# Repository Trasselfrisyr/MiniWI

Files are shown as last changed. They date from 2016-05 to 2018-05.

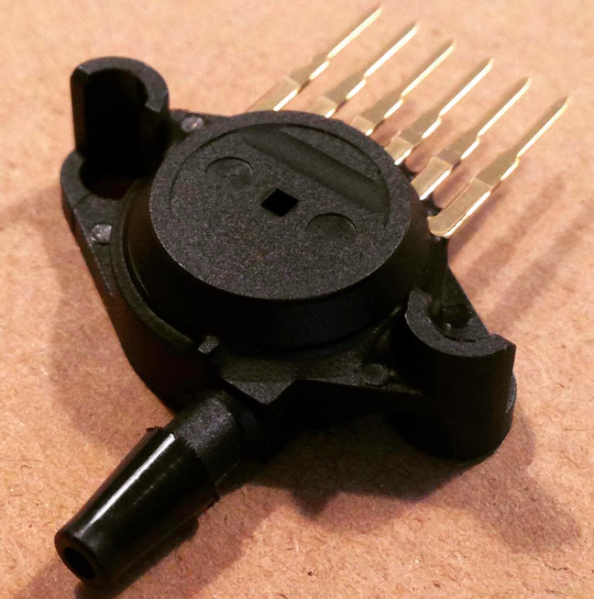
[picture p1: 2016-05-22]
Docs and references/mpx5010gp.png

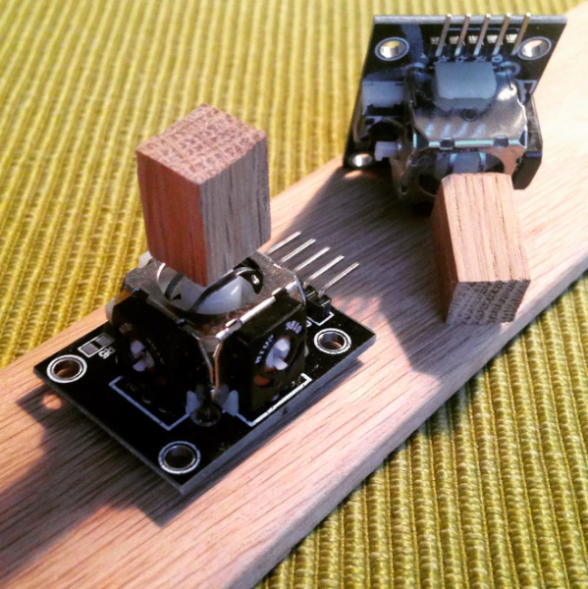
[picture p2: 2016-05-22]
Docs and references/joysticks.png

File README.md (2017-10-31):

# MiniWI
MIDI woodwind controller

2016-04-17

This MIDI controller is running on an Arduino Pro Mini with Atmega328 16MHz/5V. It makes use of breakouts for analog pins A6 and A7, so it needs a Pro Mini version with these breakouts. The pressure sensor used for the project is the Freescale MPX5010GP. Fingering is reverse engineered from Akai EWI and note values are calculated from pressed keys. For details on this, read my guest post on the Gordophone blog. 

http://gordophone.blogspot.se/2016/04/guest-post-alternative-way-of-note.html

Details on the state machine approach for handling the events is also available on Gordon's blog where I borrowed it from. He's got a step-by-step how-to on DIY wind controllers that I highly recommend.

http://gordophone.blogspot.se/2013/01/a-series-basics-of-diy-wind-controllers.html

Hardware notes for connection of MIDI, pressure sensor, keys and joysticks are available in the MiniWI.ino file.

The MIDI routines and the MIDI connections are pretty standard, but I first found them on the midikits.net website, so I'll give Tom Scarff a mention here. Kept his nice MIDI pinout ASCII sketch thing and some comment style too. 

The controller is made to work well with synthesizers using wind controller patches from Patchman Music, with the breath data sent by CC #2 (Breath). For testing I’ve been using their wind controller soundbank for Roland JV-1010.

http://www.patchmanmusic.com

Or you can make your own patches optimized for breath control. Pointers for doing that can also be found on the Patchman website.

Questions and suggestions are welcome. Just send them to johan@helgo.net.

-Johan Berglund

2016-05-17

Variations:

MiniWI.ino is the original proof of concept breadboard version with regular switches.

MiniWI-lite.ino is a simplified version (no joysticks) for my guest post on the Gordophone blog.

MiniWI-cap.ino is the capacitive touch version implemented in my first playable prototype.

MiniWI-cap-pmt.ino is a modification of the touch version to feature portamento (glide) control and a separate potentiometer for setting base octave instead of using sideways motion of joystick to increase range. This reduces instantly playable range but increases the total range of the controller.

MiniVI-cap.ino is a not yet realized EVI version (Electronic Valve Instrument) based on the Akai EVI1000 and the Steiner MIDI EVI.

2016-05-22

I’ve added some pictures from my Instagram account. Check it out for more pictures from this and my other projects.

https://www.instagram.com/trasselfrisyr/

2016-05-30

Project profile for the MiniWI added on Hackaday.io

https://hackaday.io/project/11843-miniwi-woodwind-midi-controller

2016-06-03

Added optional Casio DH 2nd octave fingerings. Default disabled. Set #define casioMod 1 to set default enabled. Hold octave stick up at power on for manual selection of the setting that is not default.

2016-06-12

Added tested and working version of the new TeensieWI, a simplified version for USB MIDI using the built in capacitive touch sensing in the Teensy LC and breath sensing from the MPX5010GP. Small warning here: the breath sensor output is not limited and could reach values near 5V, while the analog input on the Teensy LC is 3.3V and not rated 5V safe. To reach these levels you’d have to blow really, really hard. If you need to feel safe, go with a Teensy 3.1 or 3.2 as they have 5V tolerant inputs. Only minor alterations needed in the code for use with Teensy 3.x (touch sensing on other pins, some as pads on the back).

2017-10-31

Improved the joystick version of the TeensieWI, now called T.WI, with breath response curves and some other stuff that can be configured at plug-in. Started making these for sale on Tindie. https://www.tindie.com/products/yoe/twi-a-teensy-based-usb-midi-woodwind-controller/

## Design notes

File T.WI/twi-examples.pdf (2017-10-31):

# T.WI

examples

GarageBand (Mac)

GarageBand is pretty limited in how much can be configured, but many of its synth patches respond to aftertouch (channel pressure), so setting up the T.WI to send aftertouch makes it useful here. You can even keep the standard CC#2 active when activating aftertouch by holding the second RH key in combination with the pinkie key held for aftertouch.

Examples of useful synth sounds in GarageBand 10 are Saturn Lead and Soft Saw Lead.

Thor (iPad)

Now, Thor is a synth I can highly recommend. It is very flexible in its controller configuration, great sounding and not too pricey. Also there are lots of readymade patches for it intended for use with wind controllers. Patchman Music has pro grade patches (http://www.patchmanmusic.com/PropellerheadThor.html) for it with a bit higher price, but there are other options, like the set by Bernie Kenerson (http://www.berniekenerson.com/sound_design/) or even free patches for download. (http://wx5.blog2.fc2.com/blog-entry-448.html) The free patches are actually really good, but they lack mod wheel response. The Akai EWI is using MIDI pitch bend to create vibrato, so some patches made for EWI just has no mod wheel action programmed. This can be helped with some alterations to the patches of your own, or by setting the T.WI to send pitch bend vibrato by toggling the MOD setting.

To use the T.WI with these Thor patches, have it set up in its default mode, using CC#2 for the breath data.

Seaboard 5D (iPad and iPhone)

This is a free app from Roli, the makers of the expressive Seaboard controller. The Seaboard 5D app responds very well to aftertouch data, as this represents the ”press” dimension of the 5D concept.

To use it with the T.WI, we need to set up both the app and the T.WI for it. In the app, use the top right menu circle, select MIDI setup and choose Teensy MIDI as MIDI input. Select Single channel and Bend Range 12. (See their support page for more info.) (https://support.roli.com/article/all-you-need-to-know-about-seaboard-5d/) Set the T.WI to send breath data as aftertouch (AT), pitch bend (PB) to 1/12 and modulation (MOD) to send vibrato as pitch bend.

Arturia Minibrute (via USB host adapter)

The Minibrute has a connection in history with the T.WI, as the filter in the Minibrute is designed by Nyle Steiner, the same genius that invented the original EVI and EWI. For that reason, I reckon the Minibrute should be included here. Another reason for it is that the T.WI needs to be set up in a rather special way for this combination to work. First of all, the MB is a bit limited in receiving midi control data. It does receive aftertouch that can be routed to control the filter cutoff, but with no smoothing function in the digital to analog conversion for it, there is quite a bit of audible stepping in the sound as a result. The solution is to use the mod wheel control instead, as it is capable of receiving high resolution MIDI CC. That means that in addition to the seven bits of data sent on CC#1, another group of seven bits are sent on CC#33. That’s 14 bits of resolution. In reality, the resolution we get from the Teensy ADC when reading the breath sensor is 12 bits, and 12 bits is what the MB modulation wheel is sending/receiving, but that it still a whole lot more than the standard 7 bits of midi. We get 4096 steps instead of just 128.

The breath setting to use on the T.WI is CC1+33, keys LH1 and LH3 held with PB UP at USB plug-in.

Another limitation in the MB is that pitch bend range when received on MIDI is always 12 semitones up or down. That’s way too much for practical use with an EWI, so we need to compensate for that. The T.WI has two modes for pitch bend. The default one sets pitch bend to half range. Sounds great with synths set to two semitones PB range. The other one is 1/12 of the total range. This is what we will use with the MB.

Hold joystick right and RH2 key at USB plug-in to toggle this setting.

To get the breath response you want when controlling the MB, you can also try different curves for it. I’d recommend something in the -4 to -2 range.

The way to set up the MB is to route mod wheel to filter cutoff, open up the envelopes, dial down the cutoff a bit and then just muck about to find the sounds you like.

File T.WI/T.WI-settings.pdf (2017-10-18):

## Settings for T.WI

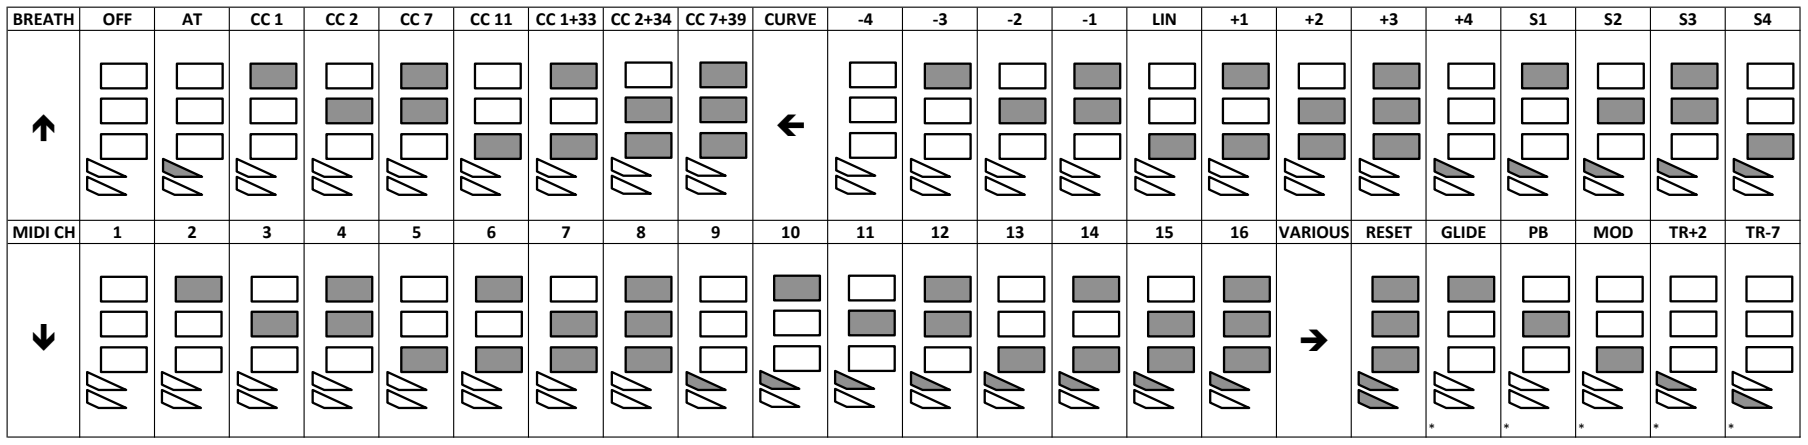
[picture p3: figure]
BREATH; OFF; CURVE; LIN; MIDI CH; VARIOUS; RESET; GLIDE; MOD

To apply settings: unplug USB, hold joystick in arrow direction, finger the RH combo for the wanted setting and plug in USB. When you see Teensy LED light up, settings have been applied and saved. Release joystick and play. To change another setting, repeat procedure.

*) This toggles current setting on/off

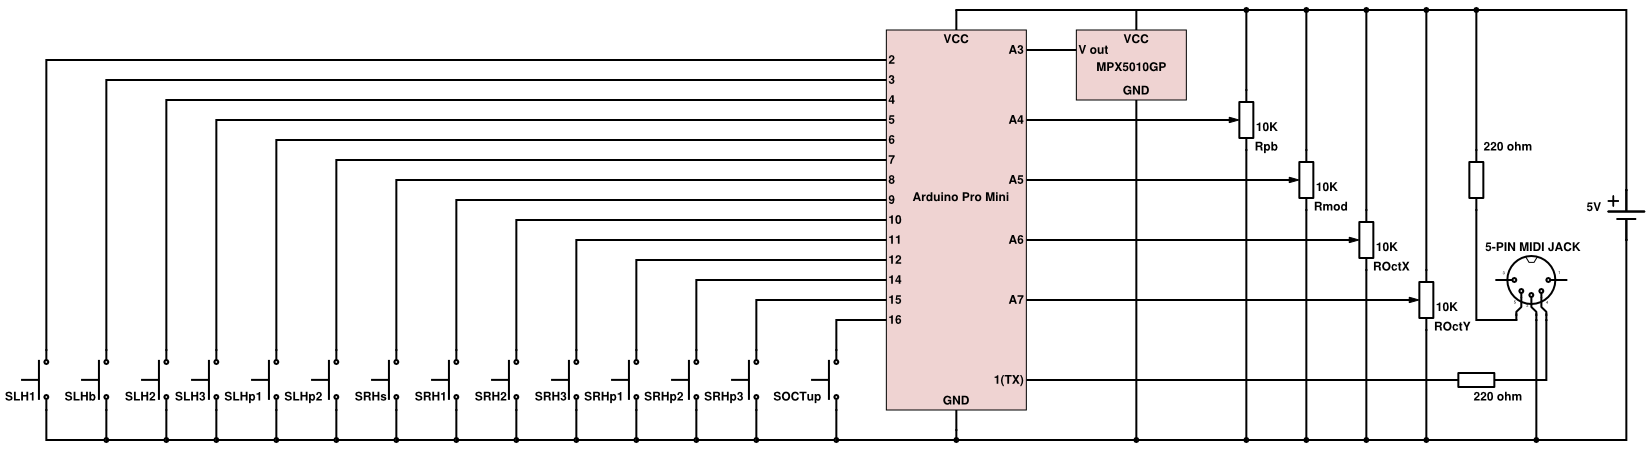
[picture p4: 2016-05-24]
MiniWI/MiniWI-schematic.png

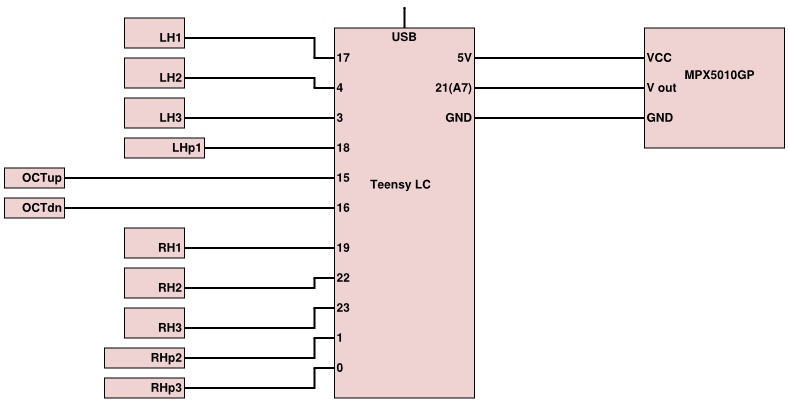
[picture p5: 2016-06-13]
TeensieWI/TeensieWI-schematic.png

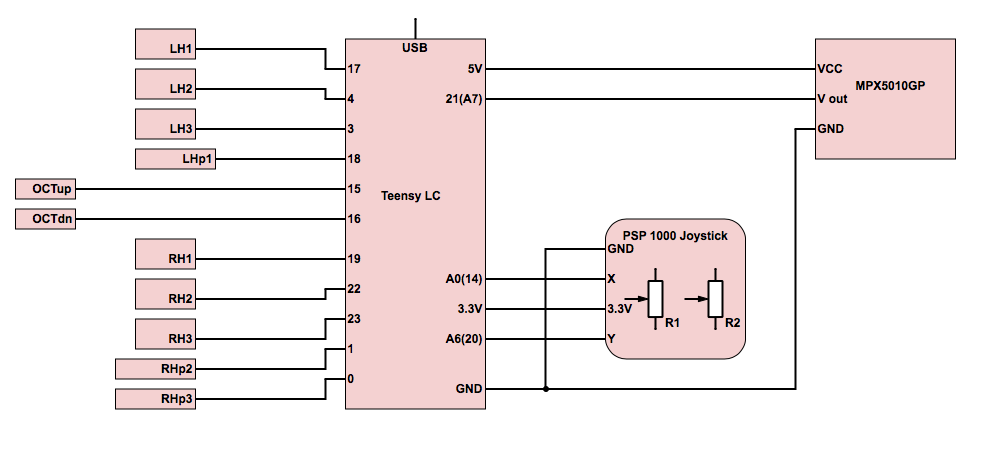
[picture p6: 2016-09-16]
T.WI/twi-schematic.png

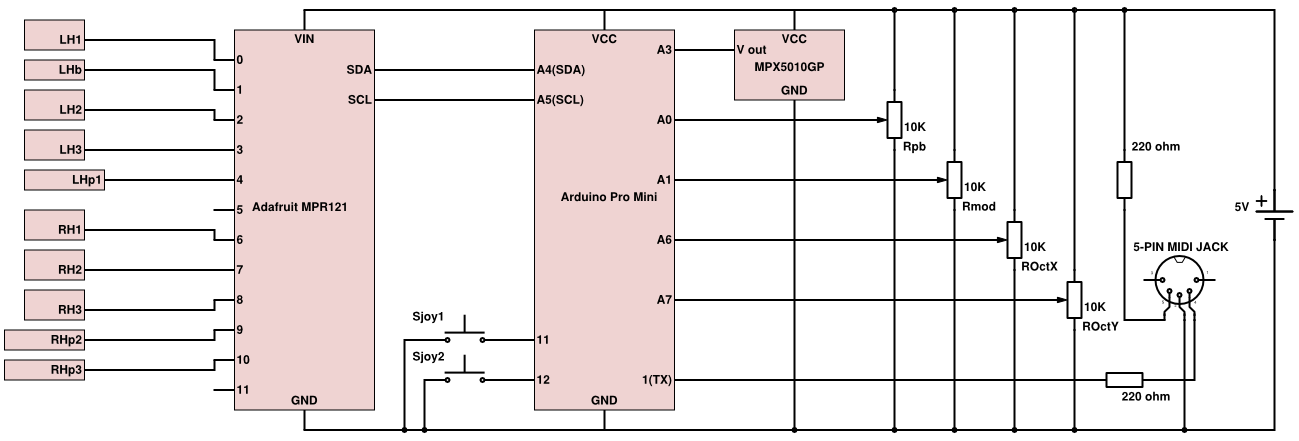
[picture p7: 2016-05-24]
MiniWI-cap/MiniWI-cap-schematic.png

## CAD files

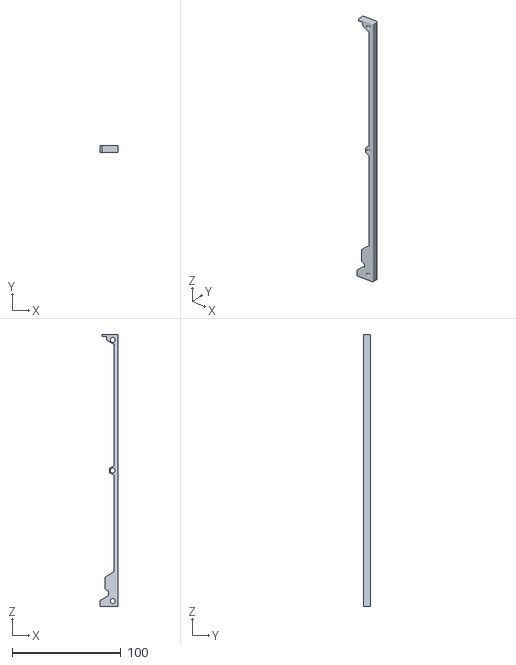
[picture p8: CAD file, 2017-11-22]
T.WI/twi-side2.stl
17.0 x 6.00 x 250.0

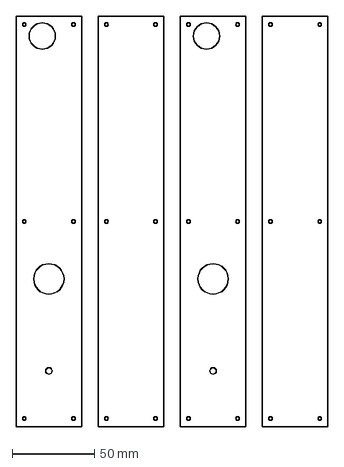
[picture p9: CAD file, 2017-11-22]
T.WI/twi-cut.dxf
190.0 x 250.0 mm

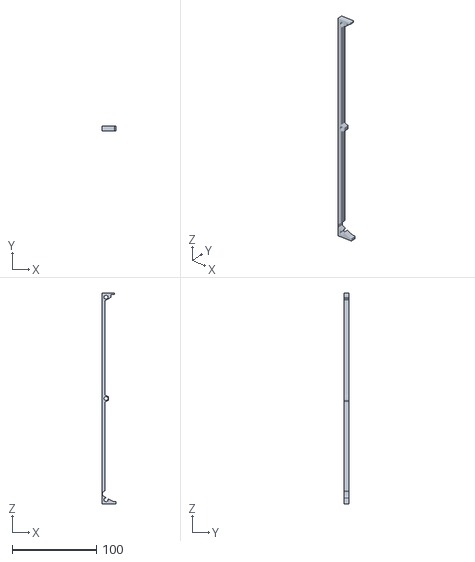
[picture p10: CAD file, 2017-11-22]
T.WI/twi-side1.stl
17.0 x 6.00 x 250.0

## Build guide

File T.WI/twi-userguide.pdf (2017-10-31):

# T.WI

user guide

The connection

T.WI is connected and powered using a micro USB to USB-A cable (the kind of cable used to charge and connect to most smartphones that are not from the fruit company). Connected to a computer or an iPad (through the Camera connection kit or an OTG adapter), it will show up in your softsynth, DAW or other software capable of receiving MIDI as ”Teensy MIDI”. With the addition of a MIDI USB host adapter (not included), it can also be connected to hardware synthesizers using DIN MIDI.

The signal

In its default setup, the T.WI transmits on MIDI channel 1, sending note on/off with a velocity based on initial breath reading, continuous breath data sent as MIDI CC#2 (breath), pitch bend limited to ½ of full value (suitable for patches with 2 semitones PB range), modulation and glide/portamento (limited to a CC level of 30 and including switching on/off).

This setup will work great with the Patchman Music wind controller soundbanks (http://www.patchmanmusic.com/WindControllerBanks.html) that are the reference standard for how wind controller patches should be. If you are making your own patches, follow the guidelines in the Patchman Music Wind Controller FAQ. (http://www.patchmanmusic.com/WindControllerFAQ.html) In cases where your synthesizer will not recognize CC#2, the T.WI can be configured to send a selection of other CC# and/or aftertouch (channel pressure) for the continuous breath data.

The controls

Unlike the Akai EWI or Casio DH, the T.WI is using a closed air path. This is the way the EWI/EVI inventor Nyle Steiner still makes his own controllers, and with good reason. More info on this can be found in the Steiner MIDI EVI owner’s manual. (http://www.patchmanmusic.com/MidiEviManualV111.pdf) The most important thing you need to know is that you are supposed to let air out by the sides of the mouthpiece when blowing into it.

Breath response can be adjusted by selecting a different curve (see the configuration chapter). The default curve is -2, which will reach mid breath value faster than a linear curve.

Top-side touch pads are the main keys for the note selection. In the fingering chart you will find the most useful fingerings. Bottom-side touch pads (LH thumb) are for going up or down one octave.

Right hand thumb controls the joystick. Moving it up or down will send pitch bend. Moving it to the left will send modulation (CC#1) and moving it to the right will activate (CC#65) and send portamento/glide (CC#5).

The configuration

To change settings, hold a combination of joystick direction and RH fingering from the settings chart while plugging in the USB. The Teensy onboard LED will flash the setting (in a cryptic way) and then the controller is ready.

Crypto key for the LED flashing: fast flashing is zero, longer flashes counts to a number. First the joystick position is shown. One is up/breath setting. Two is down/midi setting. Three is right, for various toggling settings and for factory setting restore. Four is left/breath response curve selection. Then there is the result of binary combination of the three main RH keys. This counts from zero to seven. If there is another bit, like for midi setting or breath curve, this is controlled by the first pinkie key. This key also controls aftertouch breath on in combination with the breath cc selection. The pinkie keys have their own separate flashes, either zero (four fast flashes) or one (one longer flash).

Example 1: Setting midi channel to number 11, we hold pitch bend down on the joystick and finger the combination from the chart – RH2+RHp1 – while connecting the USB to power. The LED will flash 2 - 2 - 1 - 0. (Midi channel 1 is fingering zero, so two flashes equals the value three. Plus eight from the extra bit equals eleven. Then there's the zero for the RHp2 that is not pressed. After that it's ready to play.

Example 2: Selecting the linear breath response curve. That's joystick left and RH3 at USB plug-in. LED will flash 4 - 4 - 0 - 0.

Example 3: Transpose from C to G. Joystick right and both pinkie keys at plug-in (transpose -7 to F and +2 to G). LED will flash 3 - 0 - 1 - 1. To toggle the setting back to C, do the same procedure again.

Example 4: Send breath cc (#2) and aftertouch in combination. Joystick up and RH2+RHp1 at plug-in. LED will flash 1 - 2 - 1 - 0.

Example 5: "Factory" reset. When you are completely lost in all of this, and your instrument is acting so weird you have no idea what's going on, you can reset to default values by holding joystick right and all the RH keys. LED will flash 3 - 7 -1 - 1 and then you feel safe and comfy again.

If all this sounds too complicated, it's because it is. You can just use it without changing anything and live your life as you did before all of this happened.

To get an idea what the controller is doing at any given time and have a better chance of having it do what you want it to do, a midi analyzer app for your computer or iPad is very helpful. I'm talking about stuff like MIDI Monitor on Mac or MIDI-OX on Windows. Trust me, you’ll need it if you start changing things.

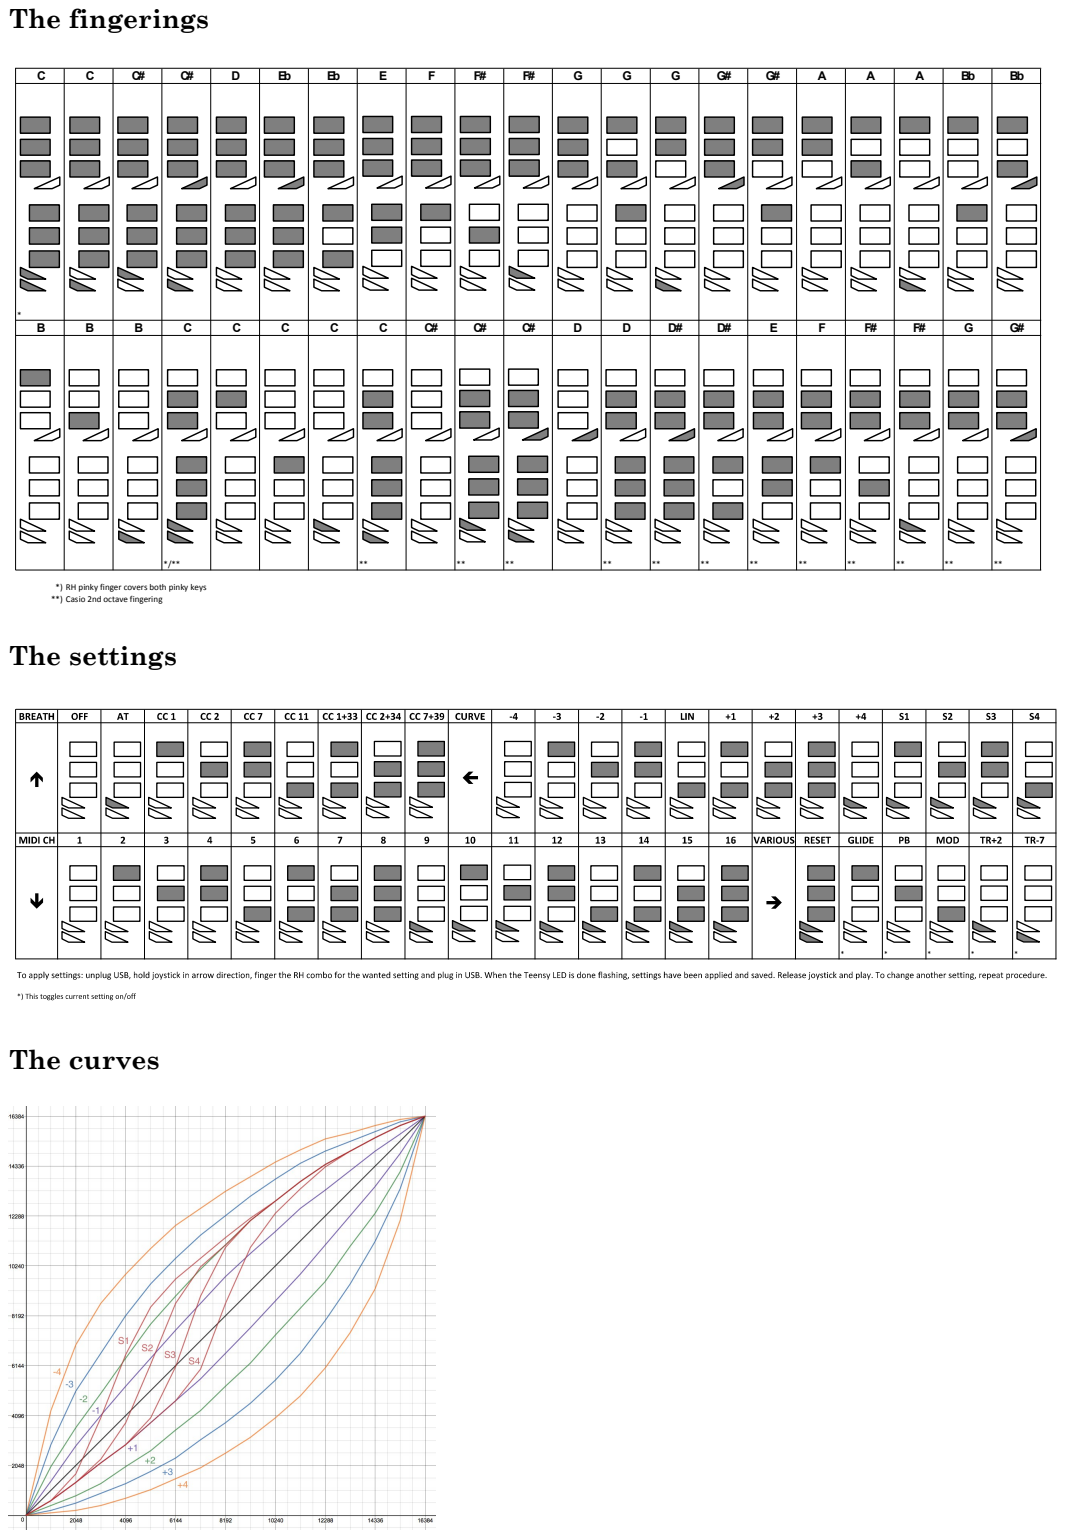
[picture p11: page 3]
The fingerings; The curves

*) RH pinky finger covers both pinky keys
**) Casio 2nd octave fingering
The settings

The little things

There are some more or less useful stuff thrown into the ”various” settings department. First of all there is a ”factory reset” that will restore all the default settings. That’s the ”RESET” in the settings chart.

The ”GLIDE” selection will toggle glide/portamento on and off. With the glide switched off, nothing will be sent when the joystick is moved to the right.

In cases where the pitch bend range of a synth can’t be set lower than 12 semitones (like the Seaboard 5D app), the ”PB” toggle setting in the T.WI will switch to sending 1/12 of max PB value.

The ”MOD” toggle setting sets the joystick left movement to send a pitch bend based vibrato instead of CC#1. This is useful for patches or synths not responding to CC#1 for vibrato (like the Seaboard 5D app), or when CC#1 is used for sending breath data. In the latter case, vibrato will always be sent as pitch bend.

To transpose the T.WI from C (default) to D, F or G, you use the TR+2 and TR-7 settings. With TR+2 you transpose up to D, with TR-7 you transpose down to F (alto mode), and with both in combination you get a transposition to G. These are also toggle settings.

The help

Should you get stuck or have issues with your controller, assistance is just an email away, and the address is johan@helgo.net.

Johan Berglund 2017

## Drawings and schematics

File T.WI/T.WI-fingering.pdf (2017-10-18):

# Fingerings for T.WI

C | C | C# | C# | D | Eb | Eb | E | F | F# | F# | G | G | G | G# | G# | A | A | A | Bb | Bb

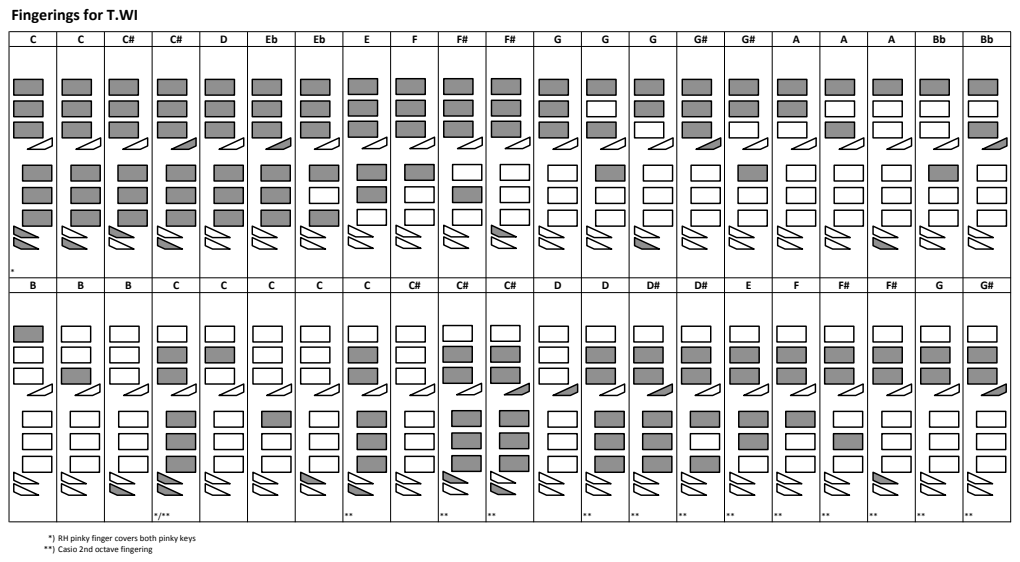
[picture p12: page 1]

B | B | B | C | C | C | C | C | C# | C# | C# | D | D | D# | D# | E | F | F# | F# | G | G#

*) RH pinky finger covers both pinky keys
**) Casio 2nd octave fingering

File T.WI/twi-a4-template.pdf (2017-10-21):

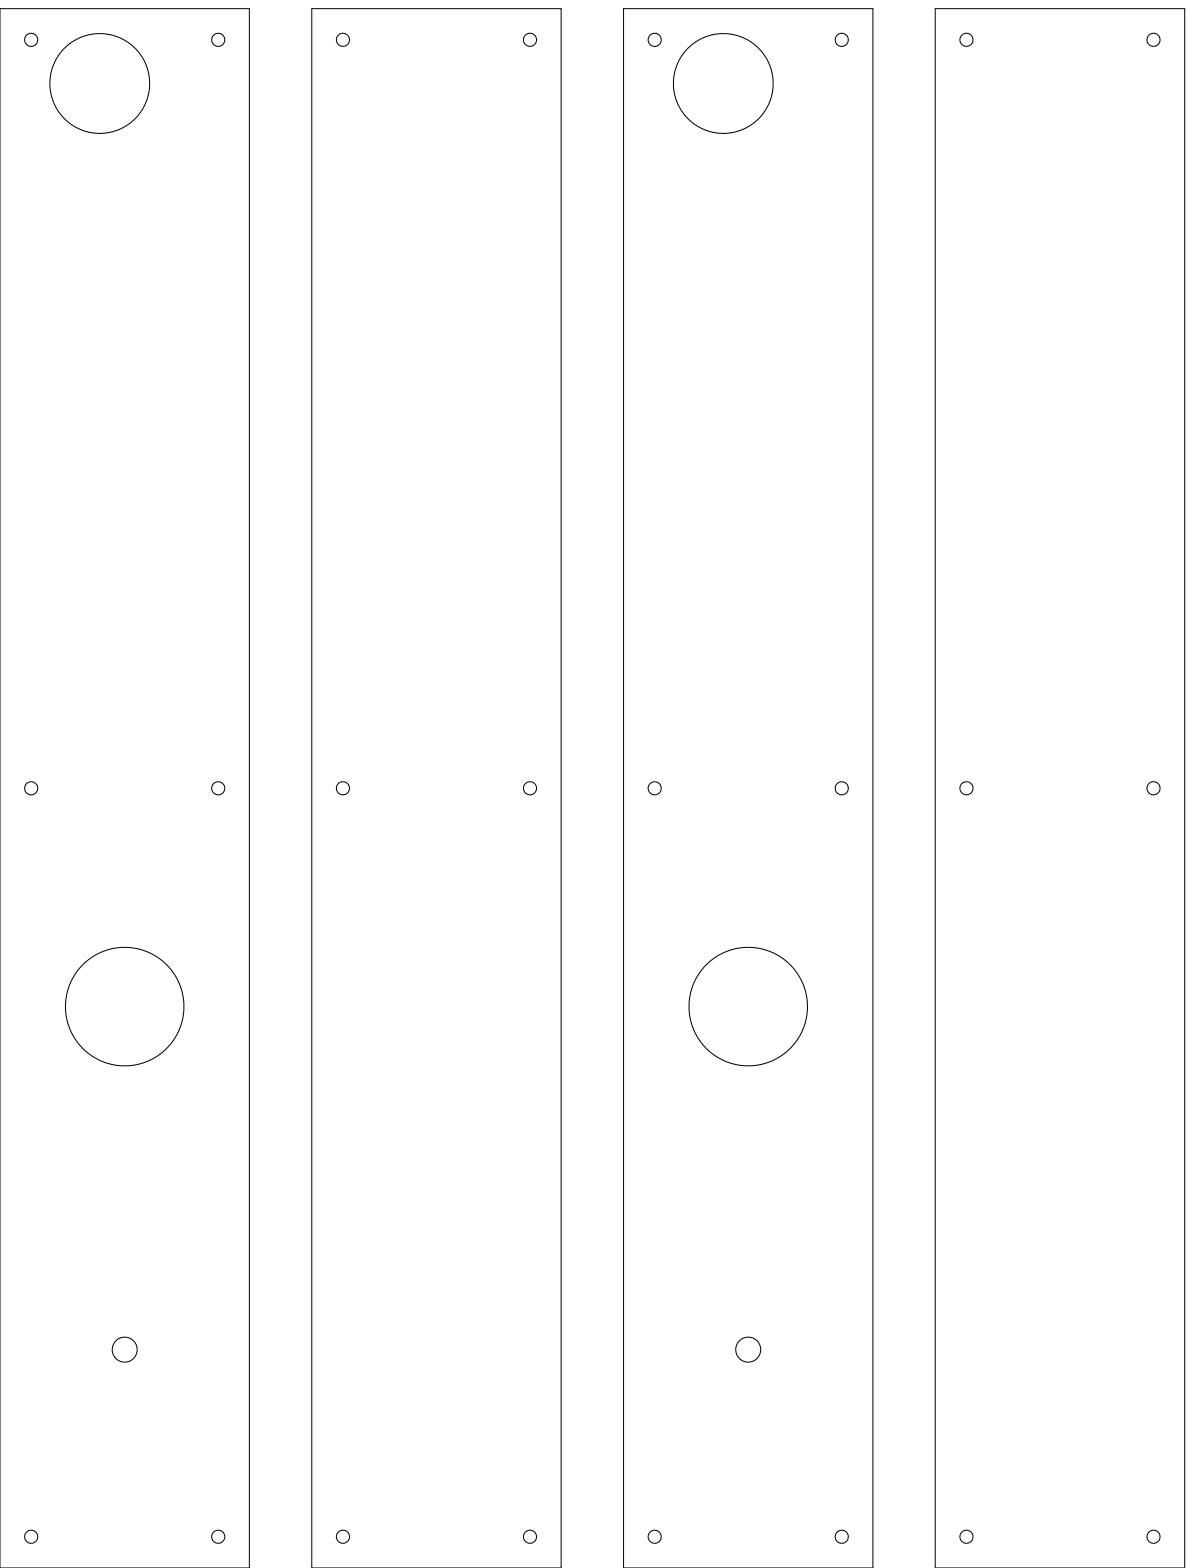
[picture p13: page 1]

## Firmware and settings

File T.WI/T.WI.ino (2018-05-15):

#include <EEPROM.h>
#include <Filters.h>  // for the breath signal LP filtering, https://github.com/edgar-bonet/Filters

/*
NAME:                 T.WI
WRITTEN BY:           JOHAN BERGLUND
DATE:                 2017-10-17
FILE SAVED AS:        T.WI.ino
FOR:                  PJRC Teensy LC and Teensyduino
CLOCK:                48.00 MHz                                       
PROGRAMME FUNCTION:   Woodwind Controller using a Freescale MPX5010GP breath sensor,
                      a PSP1000 joystick and capacitive touch keys. Output to USB MIDI.  

HARDWARE NOTES:
    
* The Freescale MPX5010GP pressure sensor output (V OUT) is connected to pin 21(A7).
* (Warning: no voltage limiting before input, can harm Teensy if excessive pressure is applied.)
* 
* Sensor pinout
* 1: V OUT (pin with indent)
* 2: GND (to GND pin of Teensy)
* 3: VCC (to 5V pin of Teensy)    
* 4: n/c
* 5: n/c
* 6: n/c
*     
* Touch sensors are using the Teensy LC built in touchRead function.
* Electrodes connect directly to Teensy pins.
* 
* PSP style thumb slide joystick controls pitch bend and modulation.
* Pitch bend and modulation are connected to pins A6 and A0.
* Connections on joystick, bottom view with connectors towards you, L to R:
* 1: to VCC 3.3V
* 2: X (or Y depending on orientation) to analog input
* 3: to GND
* 4: Y (or X depending on orientation) to analog input
* 
*     PB up
*       ^
* Mod < o > Glide
*       v
*     PB dn
*   
*/

//_______________________________________________________________________________________________ DECLARATIONS

#define touch_Thr 1500  // threshold for Teensy touchRead, 1300-1800
#define ON_Thr 300      // Set threshold level before switching ON
#define ON_Delay   20   // Set Delay after ON threshold before velocity is checked (wait for tounging peak)
#define breath_max 2200 // Threshold for maximum breath
#define modsLo_Thr 1600 // Low threshold for mod stick center
#define modsHi_Thr 2480 // High threshold for mod stick center
#define modsMin 960     // PSP joystick min value
#define modsMax 3080    // PSP joystick max value
#define PB_sen1 4096    // Pitch Bend sensitivity 0 to 8192 where 8192 is full pb range, 4096 is half range
#define PB_sen2 683     // Selectable 1/12 PB sense for synths w fixed 12 semitones pb range
#define CCN_Port 5      // Controller number for portamento level
#define CCN_PortOnOff 65// Controller number for portamento on/off
#define portaMax  30    // 1 to 127, max portamento level

// The three states of our state machine

// No note is sounding
#define NOTE_OFF 1

// We've observed a transition from below to above the
// threshold value. We wait a while to see how fast the
// breath velocity is increasing
#define RISE_WAIT 2

// A note is sounding
#define NOTE_ON 3

// Send CC data no more than every CC_INTERVAL
// milliseconds
#define CC_INTERVAL 5 

// EEPROM addresses for settings
#define VERSION_ADDR 0
#define TRANS1_ADDR 14
#define MIDI_ADDR 16
#define BREATH_CC_ADDR 18
#define BREATH_AT_ADDR 20
#define PORTAM_ADDR 24
#define PB_ADDR 26
#define EXTRA_ADDR 28
#define TRANS2_ADDR 40
#define BREATHCURVE_ADDR 44

//"factory" values for settings
#define VERSION 4
#define MIDI_FACTORY 1            // 1-16
#define BREATH_CC_FACTORY 2       // thats CC#2, see ccList
#define BREATH_AT_FACTORY 0       // aftertouch default off
#define PORTAM_FACTORY 2          // 0 - OFF, 1 - ON, 2 - SW
#define PB_FACTORY 0              // 0 - 1/2, 1 - 1/12
#define EXTRA_FACTORY 0           // 0 - Modulation wheel, 1 - Pitch Bend Vibrato
#define BREATHCURVE_FACTORY 2     // 0 to 12 (-4 to +4, S1 to S4)
#define TRANS1_FACTORY 0          // 1 - +2 semitones (C to D, F to G)
#define TRANS2_FACTORY 0          // 1 - -7 semitones (C to F, D to G) "alto mode"

#define maxSamplesNum 120

//variables setup


static int waveformsTable[maxSamplesNum] = {
  // Sine wave
  0x7ff, 0x86a, 0x8d5, 0x93f, 0x9a9, 0xa11, 0xa78, 0xadd, 0xb40, 0xba1,
  0xbff, 0xc5a, 0xcb2, 0xd08, 0xd59, 0xda7, 0xdf1, 0xe36, 0xe77, 0xeb4,
  0xeec, 0xf1f, 0xf4d, 0xf77, 0xf9a, 0xfb9, 0xfd2, 0xfe5, 0xff3, 0xffc,
  0xfff, 0xffc, 0xff3, 0xfe5, 0xfd2, 0xfb9, 0xf9a, 0xf77, 0xf4d, 0xf1f,
  0xeec, 0xeb4, 0xe77, 0xe36, 0xdf1, 0xda7, 0xd59, 0xd08, 0xcb2, 0xc5a,
  0xbff, 0xba1, 0xb40, 0xadd, 0xa78, 0xa11, 0x9a9, 0x93f, 0x8d5, 0x86a,
  0x7ff, 0x794, 0x729, 0x6bf, 0x655, 0x5ed, 0x586, 0x521, 0x4be, 0x45d,
  0x3ff, 0x3a4, 0x34c, 0x2f6, 0x2a5, 0x257, 0x20d, 0x1c8, 0x187, 0x14a,
  0x112, 0xdf, 0xb1, 0x87, 0x64, 0x45, 0x2c, 0x19, 0xb, 0x2,
  0x0, 0x2, 0xb, 0x19, 0x2c, 0x45, 0x64, 0x87, 0xb1, 0xdf,
  0x112, 0x14a, 0x187, 0x1c8, 0x20d, 0x257, 0x2a5, 0x2f6, 0x34c, 0x3a4,
  0x3ff, 0x45d, 0x4be, 0x521, 0x586, 0x5ed, 0x655, 0x6bf, 0x729, 0x794
};


int state;                         // The state of the state machine
unsigned long ccSendTime = 0L;     // The last time we sent CC values
unsigned long breath_on_time = 0L; // Time when breath sensor value went over the ON threshold
int initial_breath_value;          // The breath value at the time we observed the transition

unsigned long lastDebounceTime = 0;         // The last time the fingering was changed
unsigned long debounceDelay = 20;           // The debounce time; increase if the output flickers
int lastFingering = 0;             // Keep the last fingering value for debouncing

byte MIDIchannel=1;                // MIDI channel 1

unsigned short breathCC;           // OFF:MW:BR:VL:EX:MW+:BR+:VL+:EX+
unsigned short breathAT;
unsigned short portamento;         // switching on cc65? just cc5 enabled? SW:ON:OFF
unsigned short curve;              // selected curve
unsigned short PB;
unsigned short mod;
unsigned short trans1;
unsigned short trans2;

byte ccList[9] = {0,1,2,7,11,1,2,7,11};  // OFF, Modulation, Breath, Volume, Expression,(then same sent in hires)

int breathLevel=0;   // breath level (smoothed) not mapped to CC value
int oldbreath=0;
unsigned int oldbreathhires=0;
unsigned int breathValHires=0;

byte portIsOn=0;     // keep track and make sure we send CC with 0 value when off threshold
int oldport=0;

int pressureSensor;  // pressure data from breath sensor, for midi breath cc and breath threshold checks
byte velocitySend;   // remapped midi velocity from breath sensor

int modLevel;
int oldmod=0;
int lfoDepth=2;
int lfoLevel=0;
int lfo=0;

int pitchBend;
int oldpb=8192;
int PB_sens;
int modCCnumber = 1;

int fingeredNote;    // note calculated from fingering (switches) and octave joystick position
byte activeNote;     // note playing
byte startNote=73;   // set startNote to C# (change this value in steps of 12 to start in other octaves)

float filterFreq = 30.0; 

            // Key variables, TRUE (1) for pressed, FALSE (0) for not pressed
byte LH1;   // Left Hand key 1 (pitch change -2) 
            // Casio style 2nd octave: If LH1 is not touched when LH2 and LH3 are, pitch change +9
byte LH2;   // Left Hand key 2  (with LH1 also pressed pitch change is -2, otherwise -1)
byte LH3;   // Left Hand key 3 (pitch change -2)
byte LHp1;  // Left Hand pinky key 1 (pitch change +1)
byte RH1;   // Right Hand key 1 (with LH3 also pressed pitch change is -2, otherwise -1)
byte RH2;   // Right Hand key 2 (pitch change -1)
byte RH3;   // Right Hand key 3 (pitch change -2)
byte RHp2;  // Right Hand pinky key 2 (pitch change -1)
byte RHp3;  // Right Hand pinky key 3 (pitch change -2, in this version -1 if RHp2 is pressed)
byte OCTup; // Octave switch key (pitch change +12) 
byte OCTdn; // Octave switch key (pitch change -12) 


unsigned int curveM4[] = {0,4300,7000,8700,9900,10950,11900,12600,13300,13900,14500,15000,15450,15700,16000,16250,16383};
unsigned int curveM3[] = {0,2900,5100,6650,8200,9500,10550,11500,12300,13100,13800,14450,14950,15350,15750,16150,16383};
unsigned int curveM2[] = {0,2000,3600,5000,6450,7850,9000,10100,11100,12100,12900,13700,14400,14950,15500,16000,16383};
unsigned int curveM1[] = {0,1400,2850,4100,5300,6450,7600,8700,9800,10750,11650,12600,13350,14150,14950,15650,16838};
unsigned int curveIn[] = {0,1023,2047,3071,4095,5119,6143,7167,8191,9215,10239,11263,12287,13311,14335,15359,16383};
unsigned int curveP1[] = {0,600,1350,2150,2900,3800,4700,5600,6650,7700,8800,9900,11100,12300,13500,14850,16838};
unsigned int curveP2[] = {0,400,800,1300,2000,2650,3500,4300,5300,6250,7400,8500,9600,11050,12400,14100,16383};
unsigned int curveP3[] = {0,200,500,900,1300,1800,2350,3100,3800,4600,5550,6550,8000,9500,11250,13400,16383};
unsigned int curveP4[] = {0,100,200,400,700,1050,1500,1950,2550,3200,4000,4900,6050,7500,9300,12100,16282};
unsigned int curveS1[] = {0,600,1350,2150,2900,3800,4700,6000,8700,11000,12400,13400,14300,14950,15500,16000,16383};
unsigned int curveS2[] = {0,600,1350,2150,2900,4000,6100,9000,11000,12100,12900,13700,14400,14950,15500,16000,16383};
unsigned int curveS3[] = {0,600,1350,2300,3800,6200,8700,10200,11100,12100,12900,13700,14400,14950,15500,16000,16383};
unsigned int curveS4[] = {0,600,1700,4000,6600,8550,9700,10550,11400,12200,12900,13700,14400,14950,15500,16000,16383};

//_______________________________________________________________________________________________ SETUP

void setup() {
  analogReadResolution(12);   // set resolution of ADCs to 12 bit
  state = NOTE_OFF;           // initialize state machine
  pinMode(13,OUTPUT);         // use Teensy LED for breath on indication
  digitalWrite(13,LOW);  

  // if stored settings are not for current version, they are replaced by factory settings
  if (readSetting(VERSION_ADDR) != VERSION){
    writeSetting(VERSION_ADDR,VERSION);
    writeSetting(MIDI_ADDR,MIDI_FACTORY);
    writeSetting(TRANS1_ADDR,TRANS1_FACTORY);
    writeSetting(TRANS2_ADDR,TRANS2_FACTORY);
    writeSetting(BREATH_CC_ADDR,BREATH_CC_FACTORY);
    writeSetting(BREATH_AT_ADDR,BREATH_AT_FACTORY);
    writeSetting(PORTAM_ADDR,PORTAM_FACTORY);
    writeSetting(PB_ADDR,PB_FACTORY);
    writeSetting(EXTRA_ADDR,EXTRA_FACTORY);
    writeSetting(BREATHCURVE_ADDR,BREATHCURVE_FACTORY);
  }
  // read settings from EEPROM
  MIDIchannel  = readSetting(MIDI_ADDR);
  trans1       = readSetting(TRANS1_ADDR);
  trans2       = readSetting(TRANS2_ADDR);
  breathCC     = readSetting(BREATH_CC_ADDR);
  breathAT     = readSetting(BREATH_AT_ADDR);
  portamento   = readSetting(PORTAM_ADDR);
  PB           = readSetting(PB_ADDR);
  mod          = readSetting(EXTRA_ADDR);
  curve        = readSetting(BREATHCURVE_ADDR);

  settings();

  if (PB) PB_sens = PB_sen2; else PB_sens = PB_sen1;
  if (trans1) startNote += 2;
  if (trans2) startNote -= 7;
}

//_______________________________________________________________________________________________ MAIN LOOP

void loop() {
  mainLoop();
}
void mainLoop() {  
  FilterOnePole breathFilter( LOWPASS, filterFreq );   // create a one pole (RC) lowpass filter
  while(1){
    breathFilter.input(analogRead(A7));
    pressureSensor = constrain((int)breathFilter.output(),0,4095); // Get the filtered pressure sensor reading from analog pin A7, input from sensor MP3V5004GP
  
    if (state == NOTE_OFF) {
      if (pressureSensor > ON_Thr) {
        // Value has risen above threshold. Move to the ON_Delay
        // state. Record time and initial breath value.
        breath_on_time = millis();
        initial_breath_value = pressureSensor;
        state = RISE_WAIT;  // Go to next state
      }
    } else if (state == RISE_WAIT) {
      if (pressureSensor > ON_Thr) {
        // Has enough time passed for us to collect our second
        // sample?
        if (millis() - breath_on_time > ON_Delay) {
          // Yes, so calculate MIDI note and velocity, then send a note on event
          readSwitches();
          // We should be at tonguing peak, so set velocity based on current pressureSensor value        
          // If initial value is greater than value after delay, go with initial value, constrain input to keep mapped output within 1 to 127
          breathLevel=constrain(max(pressureSensor,initial_breath_value),ON_Thr,breath_max);
          breathValHires = breathCurve(map(constrain(breathLevel,ON_Thr,breath_max),ON_Thr,breath_max,0,16383));
          velocitySend = (breathValHires >>7) & 0x007F;
          velocitySend = constrain(velocitySend,1,127);
          breath(); // send breath data
          usbMIDI.sendNoteOn(fingeredNote, velocitySend, MIDIchannel); // send Note On message for new note 
          digitalWrite(13,HIGH);
          activeNote=fingeredNote;
          state = NOTE_ON;
        }
      } else {
        // Value fell below threshold before ON_Delay passed. Return to
        // NOTE_OFF state (e.g. we're ignoring a short blip of breath)
        state = NOTE_OFF;
      }
    } else if (state == NOTE_ON) {
      if (pressureSensor < ON_Thr) {
        // Value has fallen below threshold - turn the note off
        usbMIDI.sendNoteOff(activeNote, velocitySend, MIDIchannel); //  send Note Off message 
        digitalWrite(13,LOW);
        breathLevel=0;
        state = NOTE_OFF;
      } else {
        readSwitches();
        if (fingeredNote != lastFingering){ //
          // reset the debouncing timer
          lastDebounceTime = millis();
        }
        if ((millis() - lastDebounceTime) > debounceDelay) {
        // whatever the reading is at, it's been there for longer
        // than the debounce delay, so take it as the actual current state
          if (fingeredNote != activeNote) {
            // Player has moved to a new fingering while still blowing.
            // Send a note off for the current note and a note on for
            // the new note.      
            breathValHires = breathCurve(map(constrain(breathLevel,ON_Thr,breath_max),ON_Thr,breath_max,0,16383));
            velocitySend = (breathValHires >>7) & 0x007F;
            velocitySend = constrain(velocitySend,1,127); // set new velocity value based on current pressure sensor level
            usbMIDI.sendNoteOn(fingeredNote, velocitySend, MIDIchannel); // send Note On message for new note         
            usbMIDI.sendNoteOff(activeNote, 0, MIDIchannel); // send Note Off message for previous note (legato)
            activeNote=fingeredNote;
          }
        }
      }
    }
    // Is it time to send more CC data?
    if (millis() - ccSendTime > CC_INTERVAL) {
      // deal with Breath, Pitch Bend and Modulation
      breath();
      modulation();
      pitch_bend();
      ccSendTime = millis();
    }
    lastFingering=fingeredNote; 
  }
}
//_______________________________________________________________________________________________ FUNCTIONS

// non linear mapping function (http://playground.arduino.cc/Main/MultiMap)
// note: the _in array should have increasing values
unsigned int multiMap(unsigned int val, unsigned int* _in, unsigned int* _out, uint8_t size)
{
  // take care the value is within range
  // val = constrain(val, _in[0], _in[size-1]);
  if (val <= _in[0]) return _out[0];
  if (val >= _in[size-1]) return _out[size-1];

  // search right interval
  uint8_t pos = 1;  // _in[0] allready tested
  while(val > _in[pos]) pos++;

  // this will handle all exact "points" in the _in array
  if (val == _in[pos]) return _out[pos];

  // interpolate in the right segment for the rest
  return (val - _in[pos-1]) * (_out[pos] - _out[pos-1]) / (_in[pos] - _in[pos-1]) + _out[pos-1];
}

//**************************************************************

// map breath values to selected curve
unsigned int breathCurve(unsigned int inputVal){
  // 0 to 16383, moving mid value up or down
  switch (curve){
    case 0:
      // -4
      return multiMap(inputVal,curveIn,curveM4,17);
      break;
    case 1:
      // -3
      return multiMap(inputVal,curveIn,curveM3,17);
      break;
    case 2:
      // -2
      return multiMap(inputVal,curveIn,curveM2,17);
      break;
    case 3:
      // -1
      return multiMap(inputVal,curveIn,curveM1,17);
      break;
    case 4:
      // 0, linear
      return inputVal;
      break;
    case 5:
      // +1
      return multiMap(inputVal,curveIn,curveP1,17);
      break;
    case 6:
      // +2
      return multiMap(inputVal,curveIn,curveP2,17);
      break;
    case 7:
      // +3
      return multiMap(inputVal,curveIn,curveP3,17);
      break;
    case 8:
      // +4
      return multiMap(inputVal,curveIn,curveP4,17);
      break;
    case 9:
      // S1
      return multiMap(inputVal,curveIn,curveS1,17);
      break;
    case 10:
      // S2
      return multiMap(inputVal,curveIn,curveS2,17);
      break;
    case 11:
      // S3
      return multiMap(inputVal,curveIn,curveS3,17);
      break;
    case 12:
      // S4
      return multiMap(inputVal,curveIn,curveS4,17);
      break;
  }
}

//**************************************************************

void breath(){
  int breathCCval,breathCCvalFine;
  unsigned int breathCCvalHires;
  breathLevel = constrain(pressureSensor,ON_Thr,breath_max);
  //breathCCval = map(constrain(breathLevel,ON_Thr,breath_max),ON_Thr,breath_max,0,127);
  breathCCvalHires = breathCurve(map(constrain(breathLevel,ON_Thr,breath_max),ON_Thr,breath_max,0,16383));
  breathCCval = (breathCCvalHires >>7) & 0x007F;
  breathCCvalFine = breathCCvalHires & 0x007F;

  if (breathCCval != oldbreath){ // only send midi data if breath has changed from previous value
    if (breathCC){
      // send midi cc
      usbMIDI.sendControlChange(ccList[breathCC], breathCCval, MIDIchannel);
    }
    if (breathAT){
      // send aftertouch
      usbMIDI.sendAfterTouch(breathCCval, MIDIchannel);
    }
    oldbreath = breathCCval;
  }
  
  if (breathCCvalHires != oldbreathhires){
    if (breathCC > 4){ // send high resolution midi
        usbMIDI.sendControlChange(ccList[breathCC]+32, breathCCvalFine, MIDIchannel);
    }
    oldbreathhires = breathCCvalHires;   
  }
}

//**************************************************************

void pitch_bend(){
  pitchBend = analogRead(A0); // read voltage on analog pin A0
  if (pitchBend > modsHi_Thr){
    pitchBend = oldpb*0.6+0.4*map(constrain(pitchBend,modsHi_Thr,modsMax),modsHi_Thr,modsMax,8192,(8193 + PB_sens)); // go from 8192 to 16383 (full pb up) when off center threshold going up
  } else if (pitchBend < modsLo_Thr){
    pitchBend = oldpb*0.6+0.4*map(constrain(pitchBend,modsMin,modsLo_Thr),modsMin,modsLo_Thr,(8192 - PB_sens),8192); // go from 8192 to 0 (full pb dn) when off center threshold going down
  } else {
    pitchBend = oldpb*0.6+8192*0.4; // released, so smooth your way back to zero
    if ((pitchBend > 8187) && (pitchBend < 8197)) pitchBend = 8192; // 8192 is 0 pitch bend, don't miss it bc of smoothing
  }
  if (mod || (ccList[breathCC]==1)){
    if (PB) pitchBend += lfoLevel/6; else pitchBend += lfoLevel;
    pitchBend=constrain(pitchBend, 0, 16383);
  }
  if (pitchBend != oldpb){// only send midi data if pitch bend has changed from previous value
    usbMIDI.sendPitchBend(pitchBend, MIDIchannel);
    oldpb=pitchBend;
  }
}

//***********************************************************

void modulation(){
  int modRead = analogRead(A6); // read voltage on analog pin A6
  if (modRead < modsLo_Thr){
    modLevel = map(constrain(modRead,modsMin,modsLo_Thr),modsMin,modsLo_Thr,127,0); // go from 0 to full modulation when off center threshold going left(?)
  } else {
    modLevel = 0; // zero modulation in center position
  }
  if (modLevel != oldmod){  // only send midi data if modulation has changed from previous value
    if (!mod  && (ccList[breathCC] != modCCnumber)) usbMIDI.sendControlChange(modCCnumber, modLevel, MIDIchannel);
    oldmod=modLevel;
  }
  if (mod || (ccList[breathCC] == modCCnumber)) {
    lfo = waveformsTable[(millis()/2)%maxSamplesNum] - 2047;
    lfoLevel = lfo * modLevel / 1024 * lfoDepth;
  }
  if (portamento && (modRead > modsHi_Thr)) {    // if we are enabled and over the threshold, send portamento
   if (!portIsOn) {
      if (portamento == 2){ // if portamento midi switching is enabled
        usbMIDI.sendControlChange(CCN_PortOnOff, 127, MIDIchannel);
      }
    portIsOn=1;
    }
    int portCC;
    portCC = map(constrain(modRead,modsHi_Thr,modsMax),modsHi_Thr,modsMax,0,portaMax); // go from 0 to full when off center threshold going right(?)
    if (portCC!=oldport){
      usbMIDI.sendControlChange(CCN_Port, portCC, MIDIchannel);
    }
    oldport = portCC;        
  } else if (portIsOn) {                                    // we have just gone below threshold, so send zero value
    usbMIDI.sendControlChange(CCN_Port, 0, MIDIchannel);
    if (portamento == 2){                                   // if portamento midi switching is enabled
      usbMIDI.sendControlChange(CCN_PortOnOff, 0, MIDIchannel);
    }
    portIsOn=0;
    oldport = 0; 
  }
}

//***********************************************************

void writeSetting(byte address, unsigned short value){
  union {
    byte v[2];
    unsigned short val;
  } data;
  data.val = value;
  EEPROM.write(address, data.v[0]);
  EEPROM.write(address+1, data.v[1]);  
}

//***********************************************************

unsigned short readSetting(byte address){
  union {
    byte v[2];
    unsigned short val;
  } data;  
  data.v[0] = EEPROM.read(address); 
  data.v[1] = EEPROM.read(address+1); 
  return data.val;
}

//***********************************************************

void readSwitches(){  
  // Read switches and put value in variables
  LH1=touchRead(17)>touch_Thr;
  LH2=touchRead(4)>touch_Thr;
  LH3=touchRead(3)>touch_Thr;
  LHp1=touchRead(18)>touch_Thr;
  RH1=touchRead(19)>touch_Thr;
  RH2=touchRead(22)>touch_Thr;
  RH3=touchRead(23)>touch_Thr;
  RHp2=touchRead(1)>touch_Thr;
  RHp3=touchRead(0)>touch_Thr;
  OCTup=touchRead(15)>touch_Thr;
  OCTdn=touchRead(16)>touch_Thr;
  //calculate midi note number from pressed keys  
  fingeredNote=startNote-2*LH1-LH2-(LH2 && LH1)-2*LH3+LHp1-RH1-(RH1 && LH3)-RH2-2*RH3-RHp2-2*RHp3+(RHp2 && RHp3)+12*OCTup-12*OCTdn+9*(!LH1 && LH2 && LH3);
}

//***********************************************************
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

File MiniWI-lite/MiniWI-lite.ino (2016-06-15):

/*
NAME:                 MiniWI Lite Ver.
WRITTEN BY:           JOHAN BERGLUND
CREDITS:              State machine from the Gordophone blog by GORDON GOOD
DATE:                 2016-04-13
FILE SAVED AS:        MiniWI-lite.ino
FOR:                  Arduino Pro Mini, ATmega328
CLOCK:                16.00 MHz CRYSTAL                                        
PROGRAMME FUNCTION:   Wind Controller with EWI style key setup, Freescale MPX5010GP breath sensor 
                      and output to 5-pin DIN MIDI 

HARDWARE NOTES:
* For the MIDI connection, attach a MIDI out Female 180 Degree 5-Pin DIN socket to Arduino.
* Socket is seen from solder tags at rear.
* DIN-5 pinout is:                                         _______ 
*    pin 2 - GND                                          /       \
*    pin 4 - 220 ohm resistor to +5V                     | 1     3 |  MIDI jack
*    pin 5 - Arduino Pin 1 (TX) via a 220 ohm resistor   |  4   5  |
*    all other pins - unconnected                         \___2___/
*
* The Freescale MPX5010GP pressure sensor output (V OUT) is connected to Arduino pin A3.
* 
* Sensor pinout
* 1: V OUT (pin with indent)
* 2: GND
* 3: VCC (to 5V)    
* 4: n/c
* 5: n/c
* 6: n/c
*     
*     
* All key switches connect Ardino digital inputs (with internal pullups) to GND
* 
*/

//_______________________________________________________________________________________________ DECLARATIONS

#define ON_Thr 40       // Set threshold level before switching ON
#define ON_Delay   20   // Set Delay after ON threshold before velocity is checked (wait for tounging peak)
#define breath_max 300  // Blowing as hard as you can
#define modsLo_Thr 411  // Low threshold for mod stick center
#define modsHi_Thr 611  // High threshold for mod stick center
#define octsLo_Thr 311  // Low threshold for octave stick center
#define octsHi_Thr 711  // High threshold for octave stick center

// The three states of our state machine

// No note is sounding
#define NOTE_OFF 1

// We've observed a transition from below to above the
// threshold value. We wait a while to see how fast the
// breath velocity is increasing
#define RISE_WAIT 2

// A note is sounding
#define NOTE_ON 3

// Send CC data no more than every CC_INTERVAL
// milliseconds
#define CC_INTERVAL 40 


//variables setup

int state;                         // The state of the state machine
unsigned long ccSendTime = 0L;     // The last time we sent CC values
unsigned long breath_on_time = 0L; // Time when breath sensor value went over the ON threshold
int initial_breath_value;          // The breath value at the time we observed the transition

long lastDebounceTime = 0;         // The last time the fingering was changed
long debounceDelay = 30;           // The debounce time; increase if the output flickers
int lastFingering = 0;             // Keep the last fingering value for debouncing

byte MIDIchannel=0;                // MIDI channel 1

int breathLevel;

int pressureSensor;  // pressure data from breath sensor, for midi breath cc and breath threshold checks
byte velocity;       // remapped midi velocity from breath sensor

int fingeredNote;    // note calculated from fingering (switches) and octave joystick position
byte activeNote;     // note playing
byte startNote=61;   // set startNote to C# (change this value in steps of 12 to start in other octaves)

byte midistatus=0;
byte x;
byte LedPin = 13;    // select the pin for the LED

            // Key variables, TRUE (1) for pressed, FALSE (0) for not pressed
byte LH1;   // Left Hand key 1 (pitch change -2)
byte LHb;   // Left Hand bis key (pitch change -1 unless both LH1 and LH2 are pressed)
byte LH2;   // Left Hand key 2  (with LH1 also pressed pitch change is -2, otherwise -1)
byte LH3;   // Left Hand key 3 (pitch change -2)
byte LHp1;  // Left Hand pinky key 1 (pitch change +1)
byte LHp2;  // Left Hand pinky key 2 (pitch change -1)
byte RHs;   // Right Hand side key  (pitch change -2 unless LHp1 is pressed)
byte RH1;   // Right Hand key 1 (with LH3 also pressed pitch change is -2, otherwise -1)
byte RH2;   // Right Hand key 2 (pitch change -1)
byte RH3;   // Right Hand key 3 (pitch change -2)
byte RHp1;  // Right Hand pinky key 1 (pitch change +1)
byte RHp2;  // Right Hand pinky key 2 (pitch change -1)
byte RHp3;  // Right Hand pinky key 3 (pitch change -2)
byte OCTup; // Octave switch key (pitch change +12)



//_______________________________________________________________________________________________ SETUP

void setup() {
  pinMode(2, INPUT_PULLUP); // Set inputs with pull-up
  pinMode(3, INPUT_PULLUP); 
  pinMode(4, INPUT_PULLUP); 
  pinMode(5, INPUT_PULLUP); 
  pinMode(6, INPUT_PULLUP); 
  pinMode(7, INPUT_PULLUP); 
  pinMode(8, INPUT_PULLUP); 
  pinMode(9, INPUT_PULLUP); 
  pinMode(10, INPUT_PULLUP); 
  pinMode(11, INPUT_PULLUP); 
  pinMode(12, INPUT_PULLUP);  
  pinMode(14, INPUT_PULLUP); 
  pinMode(15, INPUT_PULLUP); 
  pinMode(16, INPUT_PULLUP);
  
  state = NOTE_OFF;  // initialize state machine
  
  pinMode(LedPin,OUTPUT);   // declare the LED's pin as output

  for (x=1; x<=4; x++){  // Do the flashy-flashy to say we are up and running
    digitalWrite( LedPin, HIGH );
    delay(300);
    digitalWrite( LedPin, LOW );
    delay(300);
  }

  Serial.begin(31250);  // start serial with midi baudrate 31250
  Serial.flush();
}

//_______________________________________________________________________________________________ MAIN LOOP
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

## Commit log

2016-04-15 Update MiniWI.ino
    Fixed typo in note calculation. Cleanup in CC sending. Cleanup and error correction in velocity calculation.
    Todo: reduce stepping in pb and mod
    [MiniWI.ino]
2016-04-15 Removed possibility of note on velocity 0 (no sound) Changed values for debounce and cc interval (had too much stepping)
    [MiniWI.ino]
2016-04-16 Typos in comments. Added technical data sheet for the Freescale MPX5010GP pressure sensor.
2016-04-17 New README.md file (rewritten) and added pdf with extensive EWI fingering chart.
2016-04-30 Added lite version and capacitive touch version. Moved original version into sub folder.
2016-05-01 Fixed error in bit selection when reading touched keys
    [MiniWI-cap.ino]
2016-05-03 Added pitch bend sensitivity. Changed startnote (center note) to 73. Swapped the octave joystick orientations.
    [MiniWI-cap.ino]
2016-05-10 New note on when fingering is changed while a note is on now gets velocity based on current breath level instead of the same velocity as the first note. Obvious difference when playing patches not se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
2016-05-10 Added midi panic function activated by depressing both joystick buttons.
    New note on when fingering is changed while a note is on now gets velocity based on current breath level instead of the same velocity as the first note. Obvious difference when playing patches not se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
2016-05-11 Added Akai EVI manual for fingering reference
2016-05-12 Flipped the octave joystick right.
    [MiniWI-cap.ino]
2016-05-17 Todo: copy legato/portamento fixes from MiniWI-cap-pmt.ino
    [MiniVI-cap.ino]
2016-05-19 Always send portamento on/off data before new notes (that are not legato played). This to make sure the value is set according to controller value when switching to patches with portamento default on.
2016-05-20 Added changes from MiniWI-cap-pmt.ino for correct handling of portamento and legato playing. Also put the octave joystick back in, with only one axis movement. Simultaneous joystick button presses fo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
    [MiniVI-cap.ino]
2016-05-24 Added schematics
2016-05-24 Added schematic.
2016-06-01 Added Casio DH 2nd octave fingering option.
2016-06-01 Fingering chart with additional Casio fingerings.
2016-06-01 Added reference sheet with Casio Digital Horn recorder fingerings.
2016-06-02 Another version of the fingering chart, now with MiniWI look on the keys.
2016-06-03 Added manual selection of Casio 2nd octave mod. Oct stick up at power on to select setting not set as default.
2016-06-09 Added TeensieWI – simple USB MIDI wind controller with just a Teensy LC and a breath sensor. Uses the built in capacitive touch sense of the Teensy. (Untested so far. Uploading as is.)
2016-06-11 Added fingering chart.
2016-06-12 Changed touch ports and corrected reading of them. Edited breath thresholds (to be further adjusted).
    [TeensieWI.ino]
2016-06-12 Removed schematic (changed).
2016-06-13 New schematic. Added info in readme file.
2016-06-14 As I connected the octave pads, I realised there was a OCTup where there should be a OCTdn in the key readings. Fixed.
    [TeensieWI.ino]
2016-06-15 Correction in note on state, where a new note could be trigged after note off, causing stuck notes.
    [MiniVI-cap.ino, MiniWI-cap-pmt.ino, MiniWI-cap.ino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]
2016-07-24 Inserted a call to breath() before sending new note. Reduced deglitching and smoothing values to get faster response. Decreased interval between CC transmissions.
2016-08-14 Version of TeensieWI using a FSR for modulation or pitch bend down.
2016-09-16 New version with a PSP 1000 joystick for pitch bend and modulation.
2016-09-16 Added schematic and picture.
2016-10-23 Send breath data before fresh notes to avoid blips if going from loud to quiet.
    [MiniWI-cap-pmt.ino]
2017-10-13 Added LED indication for breath on. Mod value wraparound fix. CC interval changed. Touch thresholds changed.
    [TeensieWI-mod.ino]
2017-10-18 New firmware for T.WI (TeensieWI, TeensyWI), with addition of selectable breath CC/AT, breath response curves and MIDI channel. Also added portamento control on joystick (that can be disabled) and op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
2017-10-21 Added fast blinking for 0 indication when changing settings. Added forgotten setting for mod to cc#74. Bug fixed: check for reset all combo last.
    [T.WI.ino]
2017-10-21 Lables for curves. Template for cutting sheets. Schematic added.
2017-10-25 Added user guide. Fixed problem with initial velocity value.
    [T.WI.ino]
2017-10-31 Changed the alternate modulation function to be pitch bend vibrato with sine LFO signal created using a sine table and the millis count. Updated readme and user guide. Added examples.
    [T.WI.ino]
2017-11-22 Added CAD files for cutting sheets and 3D-printing side pieces.
    [twi-cut.dxf, twi-side1.stl, twi-side2.stl]
2018-05-14 Replaced simple smoothing with a one pole low-pass DSP filter (https://github.com/edgar-bonet/Filters) for faster tongueing response.
    [T.WI.ino]
